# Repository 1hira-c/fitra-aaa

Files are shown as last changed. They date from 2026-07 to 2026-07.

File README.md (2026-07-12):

# fitra-aaa

Raytac **AN54LV-15**（Nordic **nRF54L15** 搭載 BLE モジュール）を中心とした、
**SlimeVR フルボディトラッカー基板**（[Smol Slime](https://docs.slimevr.dev/smol-slimes/index.html) 向け）の
KiCad 設計プロジェクトです。

## 概要

| 機能 | 部品 |
|---|---|
| MCU / BLE SoC | Raytac **AN54LV-15**（Nordic **nRF54L15** 搭載モジュール） |
| 6軸 IMU センサ | STMicroelectronics **LSM6DSV** |
| 電源管理（PMIC） | Nordic Semiconductor **NPM2100** (QFN) |
| 低周波クロック | Micro Crystal **CM8V-T1A 32.768 kHz** |
| バッテリ接続 | **VBAT / GND 独立スルーホール端子** |
| 書き込み / デバッグ | 基板上の **SWD パッド** |

## Smol Slime / SlimeVR について

本基板は、nRF 系 SoC 向けの SlimeVR トラッカー firmware「**Smol Slime**」で動作する
トラッカーハードウェアです。

- Smol Slime ドキュメント: <https://docs.slimevr.dev/smol-slimes/index.html>
- トラッカー firmware（SlimeNRF）: <https://github.com/SlimeVR/SlimeVR-Tracker-nRF>
- SlimeVR プロジェクト: <https://docs.slimevr.dev/>

## 必要環境

- **KiCad 9 以降**（回路図は KiCad 10 で保存されています。**KiCad 10 を推奨**）

## 開き方

`fitra-aaa.kicad_pro` を KiCad で開いてください。

## 外部ライブラリについて

回路図・基板で使用しているシンボル/フットプリントは設計ファイル（`*.kicad_sch` の
`lib_symbols` および `*.kicad_pcb`）に**埋め込まれている**ため、リポジトリをクローン
すればそのまま**閲覧・製造データ（ガーバー等）の生成が可能**です。外部ライブラリを
再ダウンロードしなくても基板は完全に表示されます。

部品のシンボル/フットプリントを**再編集**する場合のみ、元ライブラリが必要です。

### 同梱しているライブラリ

| ライブラリ | 内容 | ライセンス |
|---|---|---|
| `libraries/local_lib*` | 自作シンボル/フットプリント（SWD パッド, VBAT スルー, nPM2100-QFN 等） | 本プロジェクトに準ずる（CC-BY-4.0） |

### 同梱していないライブラリ（設計に埋め込み済み／再編集時に各サイトから取得）

下記の部品ライブラリは**単体ファイルとしてはリポジトリに含めていません**。各提供元の
ライセンス・利用規約により、ライブラリ単体での再配布が制限されているためです。
シンボル/フットプリントは設計ファイルに埋め込み済みなので閲覧・製造には支障ありません。

| 部品 | 取得元 | 備考 |
|---|---|---|
| NPM2100（PMIC） | [SnapEDA](https://www.snapeda.com/) | CC-BY-SA 4.0。単体ライブラリの再配布は制限あり。設計の一部としての利用は許諾 |
| LSM6DSV16XTR（IMU） | [SnapEDA](https://www.snapeda.com/) | 同上 |
| CM8V-T1A-32.768KHZ（クリスタル） | [SnapEDA](https://www.snapeda.com/) | 同上 |
| AN54LV（BLE モジュール） | [Raytac](https://www.raytac.com/) | Altium 形式。提供元規約により同梱不可 |

> 再編集が必要な場合は各提供元から入手し、`libraries/` 配下に配置のうえ
> `fp-lib-table` / `sym-lib-table` に再登録してください。

## クレジット / 帰属表示

- **NPM2100** / **LSM6DSV16XTR** / **CM8V-T1A-32.768KHZ** のシンボル・フットプリント・3D モデルは
  [SnapEDA](https://www.snapeda.com/)（CC-BY-SA 4.0）提供のものを設計に組み込んで使用しています。

## ライセンス

本リポジトリの設計データ（回路図・基板・自作ライブラリ）は
**Creative Commons Attribution 4.0 International (CC-BY-4.0)** で公開します。

同梱・参照する各部品ライブラリは、それぞれの提供元（SnapEDA, Raytac 等）
のライセンス・利用規約に従います。

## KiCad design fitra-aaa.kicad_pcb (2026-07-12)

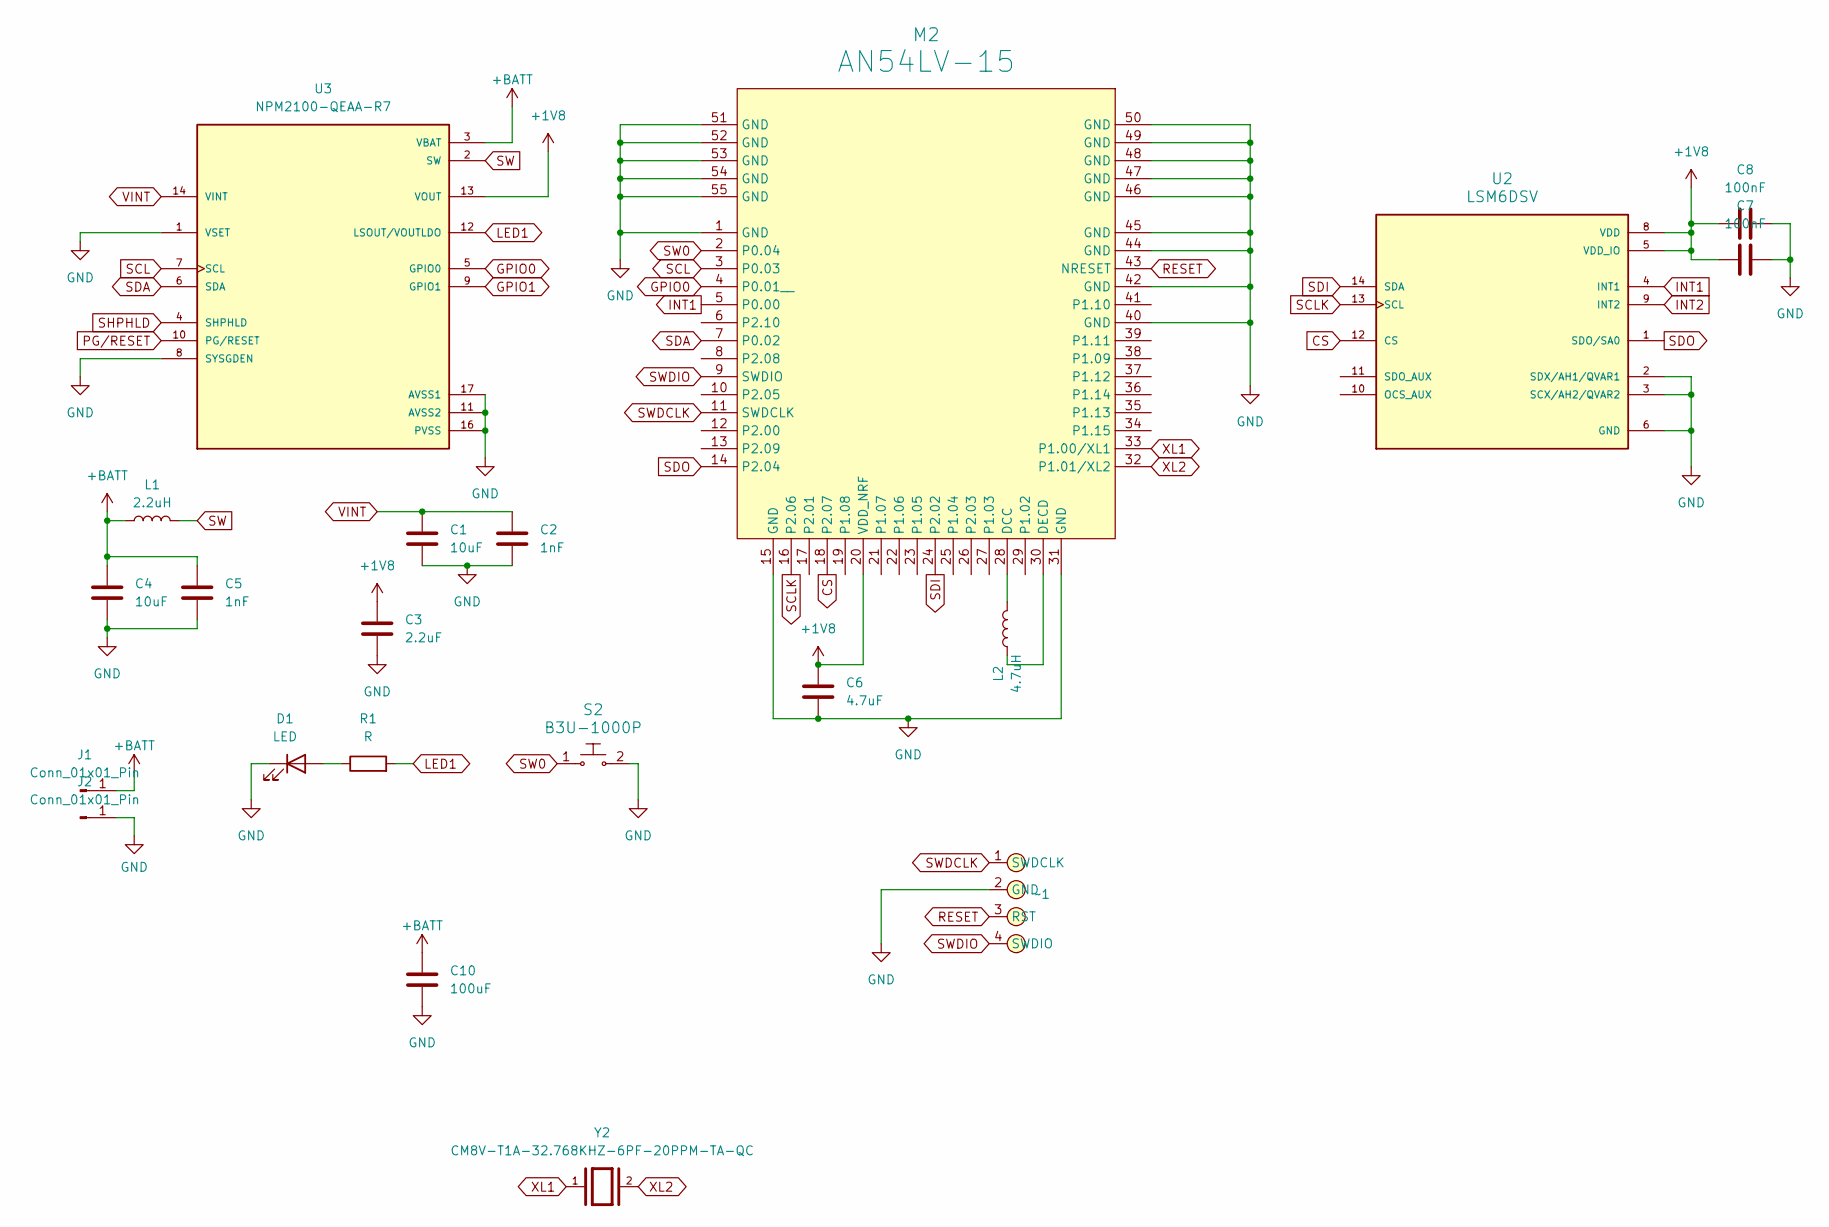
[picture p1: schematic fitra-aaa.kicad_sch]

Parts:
C1, C4: 10uF; C_0402_1005Metric
C2, C5: 1nF; C_0201_0603Metric
C3: 2.2uF; C_0402_1005Metric
C6: 4.7uF; C_0402_1005Metric
C7, C8: 100nF; C_0402_1005Metric
C10: 100uF; C_0805_2012Metric
D1: LED; LED_2-SMD_No_Lead_1.7x0.8mm
J1, J2: Conn_01x01_Pin; Pin_D0.7mm_L6.5mm_W1.8mm_FlatFork
L1: 2.2uH; L_0603_1608Metric
L2: 4.7uH; L_0603_1608Metric
M2: AN54LV-15
R1: R; R_0603_1608Metric
S2: B3U-1000P; Switch_Tactile_SMD_B3U-1000P; MPN B3U-1000P; Digi-Key_PN SW1020CT-ND
U2: LSM6DSV; XDCR_LSM6DSV16XTR; PARTREV 4
U3: NPM2100-QEAA-R7; QFN65P400X400X90-17N; PARTREV 1.0
Y2: CM8V-T1A-32.768KHZ-6PF-20PPM-TA-QC; XTAL_CM8V-T1A-32.768KHZ-6PF-20PPM-TA-QC; PARTREV 8.1/11.2018; DigiKey_Part_Number 2195-CM8V-T1A-32.768KHZ-6PF-20PPM-TA-QC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
~1: SWD_Pad

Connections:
+1V8: C3.1, C6.1, C7.1, C8.1, M2.20 (VDD_NRF), U2.5 (VDD_IO), U2.8 (VDD), U3.13 (VOUT)
+BATT: C4.1, C5.1, C10.1, J1.1 (Pin_1_1), L1.1, U3.3 (VBAT)
CS: M2.18 (P2.07), U2.12 (CS)
GND: C1.2, C2.2, C3.2, C4.2, C5.2, C6.2, C7.2, C8.2, C10.2, D1.1 (K), J2.1 (Pin_1_1), M2.1 (GND), M2.15 (GND), M2.31 (GND), M2.40 (GND), M2.42 (GND), M2.44 (GND), M2.45 (GND), M2.46 (GND), M2.47 (GND), M2.48 (GND), M2.49 (GND), M2.50 (GND), M2.51 (GND), M2.52 (GND), M2.53 (GND), M2.54 (GND), M2.55 (GND), S2.2, U2.2 (SDX/AH1/QVAR1), U2.3 (SCX/AH2/QVAR2), U2.6 (GND), U2.7 (GND), U3.1 (VSET), U3.8 (SYSGDEN), U3.11 (AVSS2), U3.16 (PVSS), U3.17 (AVSS1), ~1.2 (GND)
GPIO0: M2.4 (P0.01__), U3.5 (GPIO0)
GPIO1: U3.9 (GPIO1)
INT1: M2.5 (P0.00), U2.4 (INT1)
INT2: U2.9 (INT2)
LED1: R1.2, U3.12 (LSOUT/VOUTLDO)
unnamed: D1.2 (A), R1.1
unnamed: L2.2, M2.28 (DCC)
unnamed: L2.1, M2.30 (DECD)
PG/RESET: U3.10 (PG/RESET)
RESET: M2.43 (NRESET), ~1.3 (RST)
SCL: M2.3 (P0.03), U3.7 (SCL)
SCLK: M2.16 (P2.06), U2.13 (SCL)
SDA: M2.7 (P0.02), U3.6 (SDA)
SDI: M2.24 (P2.02), U2.14 (SDA)
SDO: M2.14 (P2.04), U2.1 (SDO/SA0)
SHPHLD: U3.4 (SHPHLD)
SW: L1.2, U3.2 (SW)
SW0: M2.2 (P0.04), S2.1
SWDCLK: M2.11 (SWDCLK), ~1.1 (SWDCLK)
SWDIO: M2.9 (SWDIO), ~1.4 (SWDIO)
VINT: C1.1, C2.1, U3.14 (VINT), U3.15 (VINT)
XL1: M2.33 (P1.00/XL1), Y2.1
XL2: M2.32 (P1.01/XL2), Y2.2

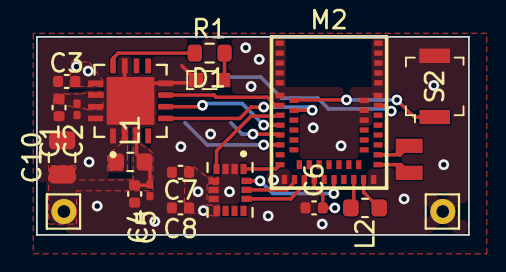
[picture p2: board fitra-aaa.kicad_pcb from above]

Board: 4 copper layers, 24.0 x 11.0 mm, 20 parts (0 on the bottom side), 20 nets.

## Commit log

2026-06-06 Public release commit
    Raytac AN54LQ-15（Nordic nRF54L15 搭載 BLE モジュール）を中心とした、SlimeVR フルボディトラッカー基板（Smol Slime 向け）の KiCad 設計プロジェクト。LSM6DSV16XTR IMU、NPM2100 PMIC、JST SM03B バッテリコネクタを搭載。
    サードパーティの部品ライブラリ（SnapEDA / Raytac / Ultra Librarian）は単体ファイルとしては再配布せず、シンボル/フットプリントは設計ファイルに埋め込み済み。リポジトリに同梱するのは自作の local_lib のみ。設計データは CC-BY-4.0 で公開。
    [fitra-aaa.kicad_pcb, fitra-aaa.kicad_sch]
2026-07-12 Update board for AN54LV module
    [fitra-aaa.kicad_pcb, fitra-aaa.kicad_sch]
